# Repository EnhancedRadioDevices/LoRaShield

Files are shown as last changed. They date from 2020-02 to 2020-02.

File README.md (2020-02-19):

LoRaShield2.1 Hardware

These are the hardware design files for the LoRaShield2.1 electronics.

These hardware files were created with KiCAD. 
You may need the KiCAD libraries available here: https://github.com/mogar/KiCAD_libs
When opening these projects in KiCAD, you may need to change the path to the libraries from the above link.
This can be done in preferences->libraries in both the schematic editor and the layout editor.
Make sure the libraries noted there point to wherever you put the above KiCAD_libs repo.

# Arduino Library

Check out these libraries:

* https://github.com/EnhancedRadioDevices/LoRaHam
* https://github.com/EnhancedRadioDevices/LoRaChat

# LoRaShield 2.1 Pinout

LoRaShield uses the SPI pins on your Arduino. It also uses a couple of digital pins for reset and interrupt.

    Arduino <-> LoRaShield
    D2          interrupt
    D3          reset
    D10         SPI SS
    D11         SPI MOSI
    D12         SPI MISO
    D13         SPI SCK

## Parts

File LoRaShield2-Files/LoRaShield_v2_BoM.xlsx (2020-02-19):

Id | Designator | Package | Quantity | Designation | MFR | MFR PN | Supplier | Supplier PN
1 | C1 | C_0603 | 1 | 4u7 | Samsung Electro-Mechanics | CL10A475MP5LNNC | DigiKey | 1276-6684-1-ND
2 | C2,C6,C11 | C_0603 | 2 | 1u | Samsung Electro-Mechanics | CL10B105KP8NNNC | DigiKey | 1276-1946-1-ND
3 | C3,C7,C8,C9,C10 | C_0603 | 5 | 0u1 | Samsung Electro-Mechanics | CL10F104ZB8NNNC | DigiKey | 1276-1012-1-ND
4 | D1 | D_0603 | 1 | green LED | Lite-On | LTST-C190KGKT | DigiKey | 160-1435-2-ND
5 | J1 | SMA-EDGE-HandSolder | 1 | SMA_EDGE | DNP | DNP | DNP | DNP
6 | U1 | RFM98PW | 1 | RFM95PW - 915MHz | Hope RF | RFM95PW | Enhanced Radio Devices
6 | U1 | RFM98PW | 1 | RFM95PW -137MHz | Hope RF | RFM95PW | Enhanced Radio Devices
6 | U1 | RFM98PW | 1 | RFM95PW - 440MHz | Hope RF | RFM95PW | Enhanced Radio Devices
7 | C4,C5 | C_0603 | 2 | 6p | Samsung Electro-Mechanics | CL10C060CB8NNNC | DigiKey | 1276-2133-1-ND
8 | L2 | L_0603 | 1 | 18n | Murata | LQW18AN18NJ00D | DigiKey | 490-1172-1-ND
9 | J2 | Pin_Header_Straight_2x20_Pitch2.54mm | 1 | Conn_02x20_Odd_Even | DNP | DNP | DNP | DNP
10 | U2,U3 | USON-20_2x4mm_Pitch0.4mm | 2 | TXB0108DQSR | Texas Instruments | TXB0108DQSR | DigiKey | 296-27217-1-ND
11 | R1 | R_0603 | 1 | 1M | Rohm Semiconductor | ESR03EZPJ105 | DigiKey | RHM1MDCT-ND
12 | R2 | R_0603 | 1 | 330 | Panasonic | ERJ-3GEYJ331V | DigiKey | P330GCT-ND
13 | J3 | Pin_Header_Straight_2x06_Pitch2.54mm | 1 | Conn_02x06_Odd_Even | DNP | DNP | DNP | DNP
14 | R3,R5 | R_0402 | 2 | 0 | Vishay Dale | CRCW04020000Z0ED | DigiKey | 541-0.0JTR-ND
15 | R4 | R_0402 | 1 | DNP | DNP | DNP | DNP | DNP

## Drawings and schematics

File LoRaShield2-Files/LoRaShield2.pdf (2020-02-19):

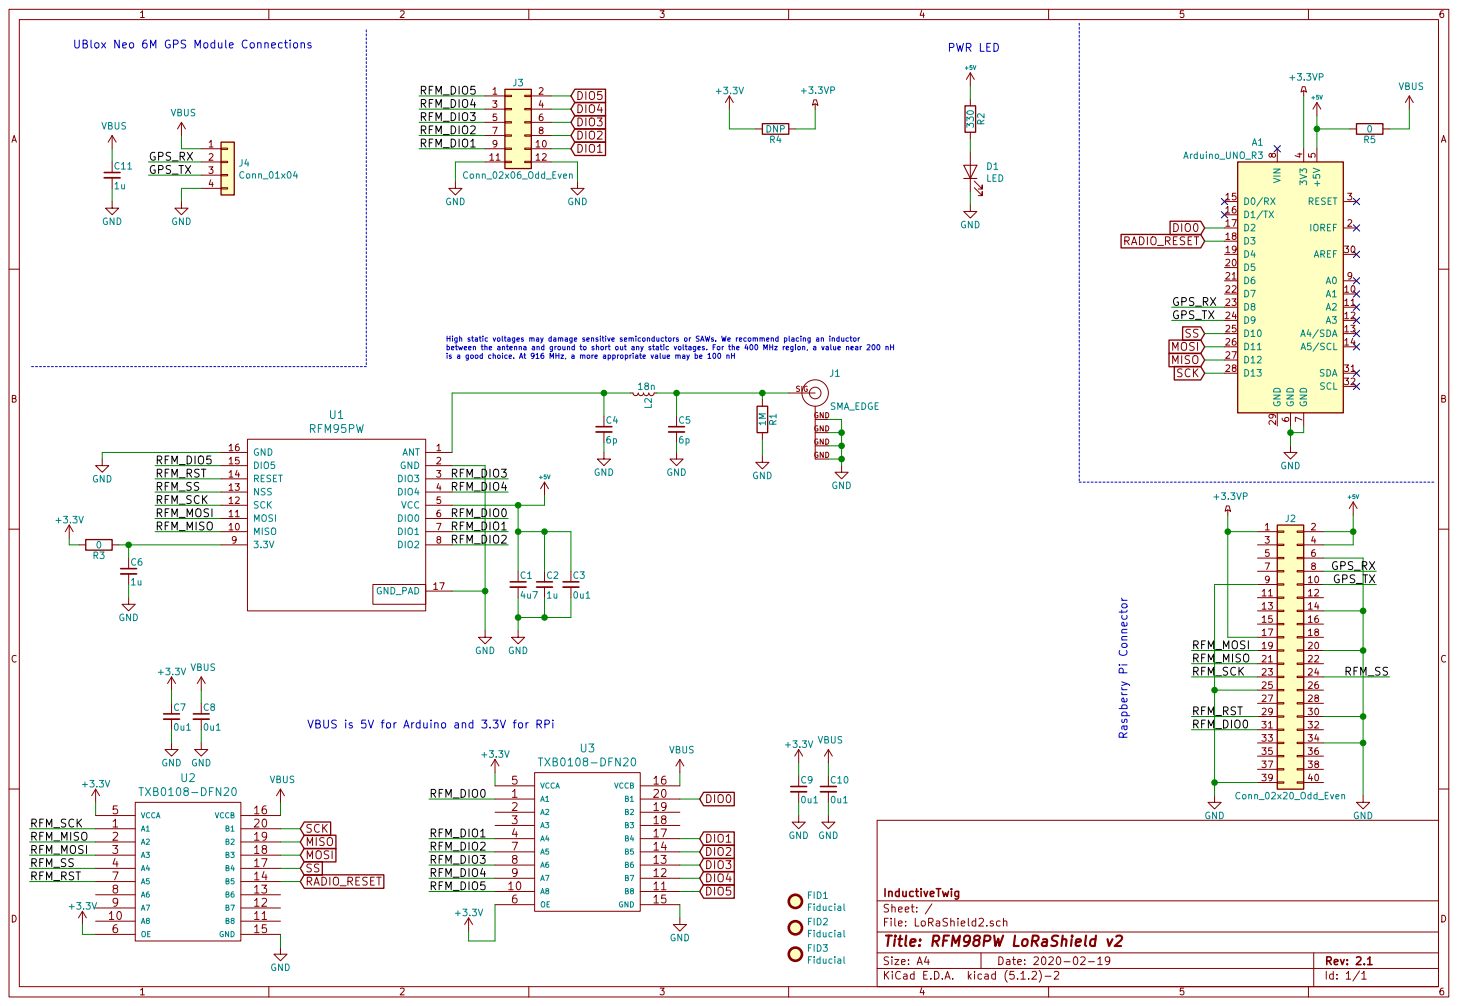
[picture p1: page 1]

UBlox Neo 6M GPS Module Connections VBUS C11

VBUS VBUS is 5V for Arduino and 3.3V for RPi VBUS

8 A0 9 A1 10 D5 20 AREF 30 A2 11 D6 21 SDA 31 A3 12 D7 22 SCL 32 A4/SDA 13 D8 23 A5/SCL 14 D9 24 D0/RX 15 D10 25 D1/TX 16 D11 26 D2 17 D12 27 D3 18 D13 28 D4 19 GND 29 A1 Arduino_UNO_R3 GND

High static voltages may damage sensitive semiconductors or SAWs. We recommend placing an inductor between the antenna and ground to short out any static voltages. For the 400 MHz region, a value near 200 nH

RFM_DIO3
RFM_DIO4

19 | | 20
21 | 22
23 | 26

31 | 32
33 35 37 39 | | 34

A5 7
A6 8

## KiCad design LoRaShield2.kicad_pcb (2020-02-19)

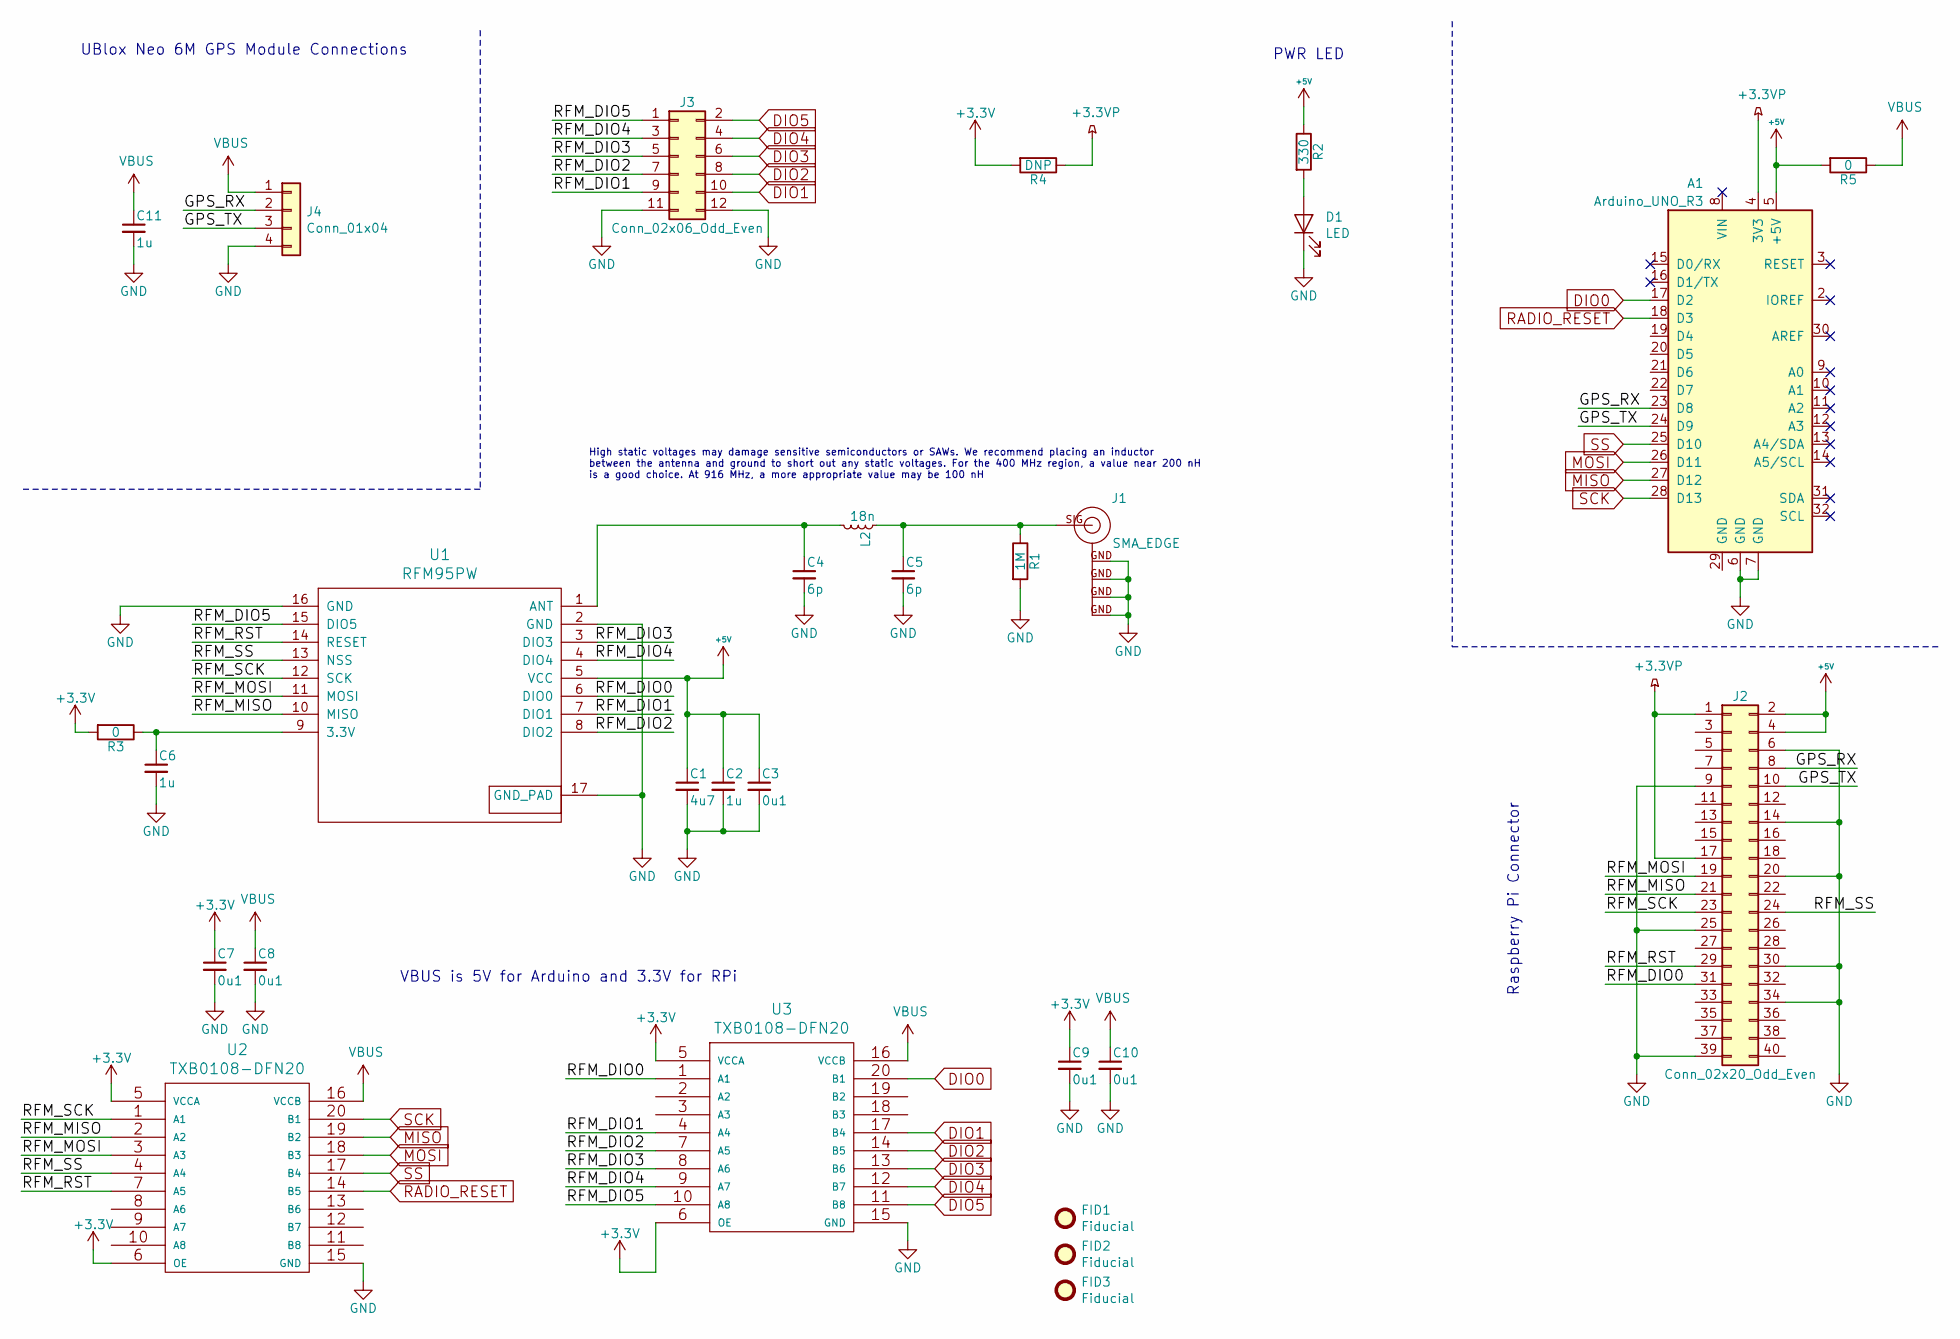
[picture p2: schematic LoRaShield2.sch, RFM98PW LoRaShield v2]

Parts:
A1: Arduino_UNO_R3; Arduino_UNO_HamShieldFootprint
C1: 4u7; C_0603
C2, C6, C11: 1u; C_0603
C3, C7, C8, C9, C10: 0u1; C_0603
C4, C5: 6p; C_0603
D1: LED; D_0603
FID1, FID2, FID3: Fiducial; Fiducial_0.5mm_Dia_1mm_Outer
J1: SMA_EDGE; SMA-EDGE-HandSolder
J2: Conn_02x20_Odd_Even; Pin_Header_Straight_2x20_Pitch2.54mm
J3: Conn_02x06_Odd_Even; Pin_Header_Straight_2x06_Pitch2.54mm
J4: Conn_01x04; Pin_Header_Straight_1x04_Pitch2.54mm
L2: 18n; L_0603
R1: 1M; R_0603
R2: 330; R_0603
R3, R5: 0; R_0402
R4: DNP; R_0402
U1: RFM95PW; RFM98PW
U2, U3: TXB0108-DFN20; USON-20_2x4mm_Pitch0.4mm

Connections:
+3.3VP: A1.4 (3V3), J2.1, J2.17, R4.1
+3V3: C7.1, C9.1, R3.2, R4.2, U2.5 (VCCA), U2.6 (OE), U3.5 (VCCA), U3.6 (OE)
+5V: A1.5 (+5V), C1.1, C2.1, C3.1, J2.2, J2.4, R2.1, R5.2, U1.5 (VCC)
/GPS_RX: A1.23 (D8), J2.8, J4.2
/GPS_TX: A1.24 (D9), J2.10, J4.3
/RFM_DIO0: J2.31, U1.6 (DIO0), U3.1 (A1)
/RFM_DIO1: J3.9, U1.7 (DIO1), U3.4 (A4)
/RFM_DIO2: J3.7, U1.8 (DIO2), U3.7 (A5)
/RFM_DIO3: J3.5, U1.3 (DIO3), U3.8 (A6)
/RFM_DIO4: J3.3, U1.4 (DIO4), U3.9 (A7)
/RFM_DIO5: J3.1, U1.15 (DIO5), U3.10 (A8)
/RFM_MISO: J2.21, U1.10 (MISO), U2.2 (A2)
/RFM_MOSI: J2.19, U1.11 (MOSI), U2.3 (A3)
/RFM_RST: J2.29, U1.14 (RESET), U2.7 (A5)
/RFM_SCK: J2.23, U1.12 (SCK), U2.1 (A1)
/RFM_SS: J2.24, U1.13 (NSS), U2.4 (A4)
DIO0: A1.17 (D2), U3.20 (B1)
DIO1: J3.10, U3.17 (B4)
DIO2: J3.8, U3.14 (B5)
DIO3: J3.6, U3.13 (B6)
DIO4: J3.4, U3.12 (B7)
DIO5: J3.2, U3.11 (B8)
GND: A1.6 (GND), A1.7 (GND), C1.2, C2.2, C3.2, C4.2, C5.2, C6.2, C7.2, C8.2, C9.2, C10.2, C11.2, D1.1 (K), J1.GND, J2.6, J2.9, J2.14, J2.20, J2.25, J2.30, J2.34, J2.39, J3.11, J3.12, J4.4, R1.2, U1.2 (GND), U1.16 (GND), U1.17 (GND_PAD), U2.15 (GND), U3.15 (GND)
MISO: A1.27 (D12), U2.19 (B2)
MOSI: A1.26 (D11), U2.18 (B3)
unnamed: C4.1, L2.2, U1.1 (ANT)
unnamed: C5.1, J1.SIG (SIGNAL), L2.1, R1.1
unnamed: C6.1, R3.1, U1.9 (3.3V)
unnamed: D1.2 (A), R2.2
RADIO_RESET: A1.18 (D3), U2.14 (B5)
SCK: A1.28 (D13), U2.20 (B1)
SS: A1.25 (D10), U2.17 (B4)
VBUS: C8.1, C10.1, C11.1, J4.1, R5.1, U2.16 (VCCB), U3.16 (VCCB)

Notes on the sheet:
High static voltages may damage sensitive semiconductors or SAWs. We recommend placing an inductor between the antenna and ground to short out any static voltages. For the 400 MHz region, a value near 200 nH is a good choice. At 916 MHz, a more appropriate value may be 100 nH
Raspberry Pi Connector
VBUS is 5V for Arduino and 3.3V for RPi
PWR LED
UBlox Neo 6M GPS Module Connections

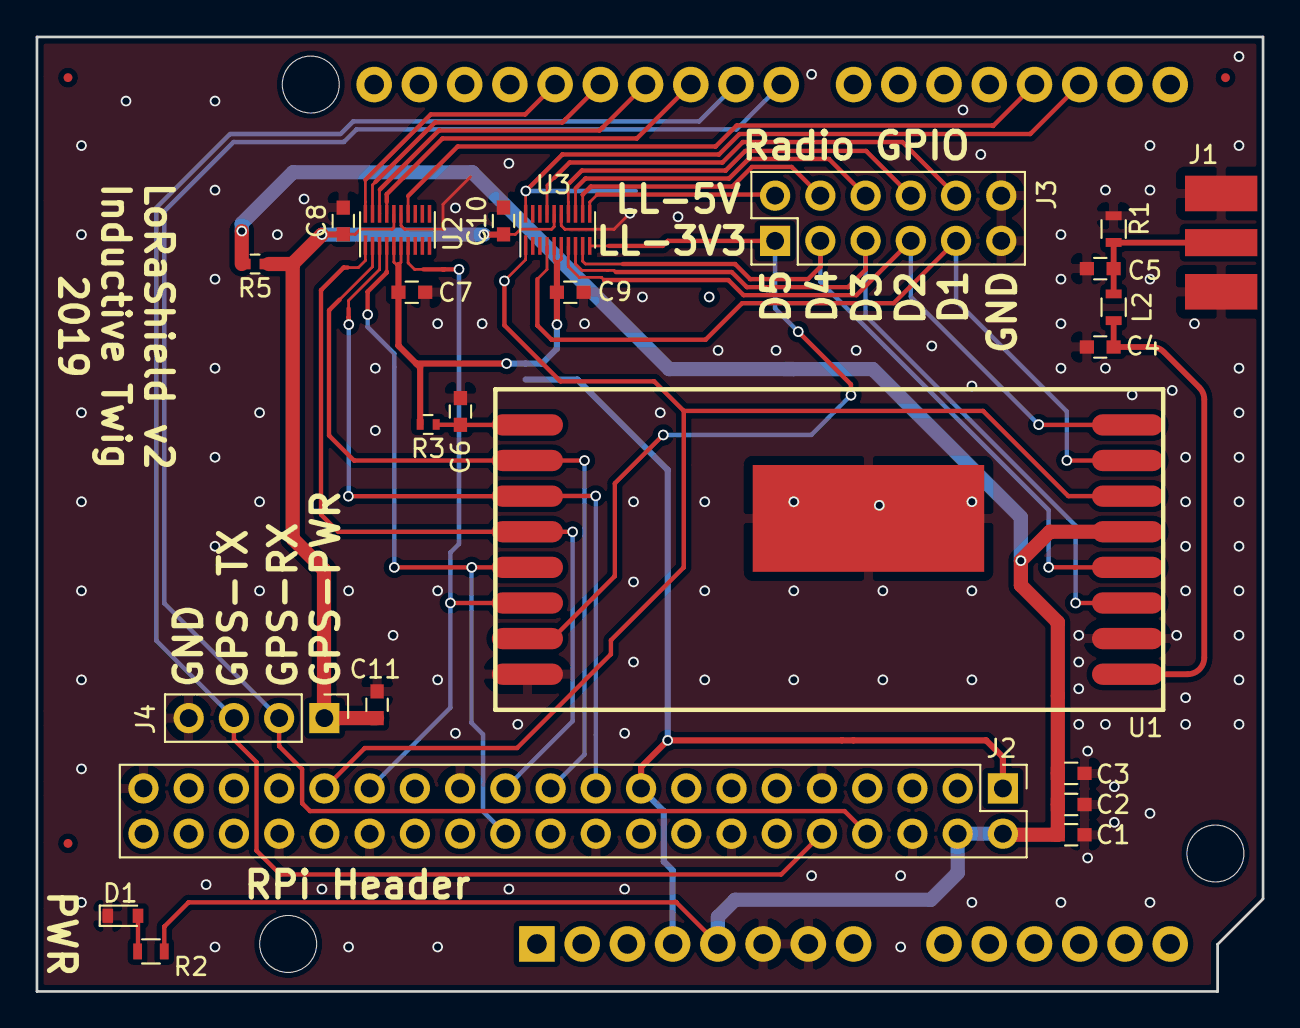
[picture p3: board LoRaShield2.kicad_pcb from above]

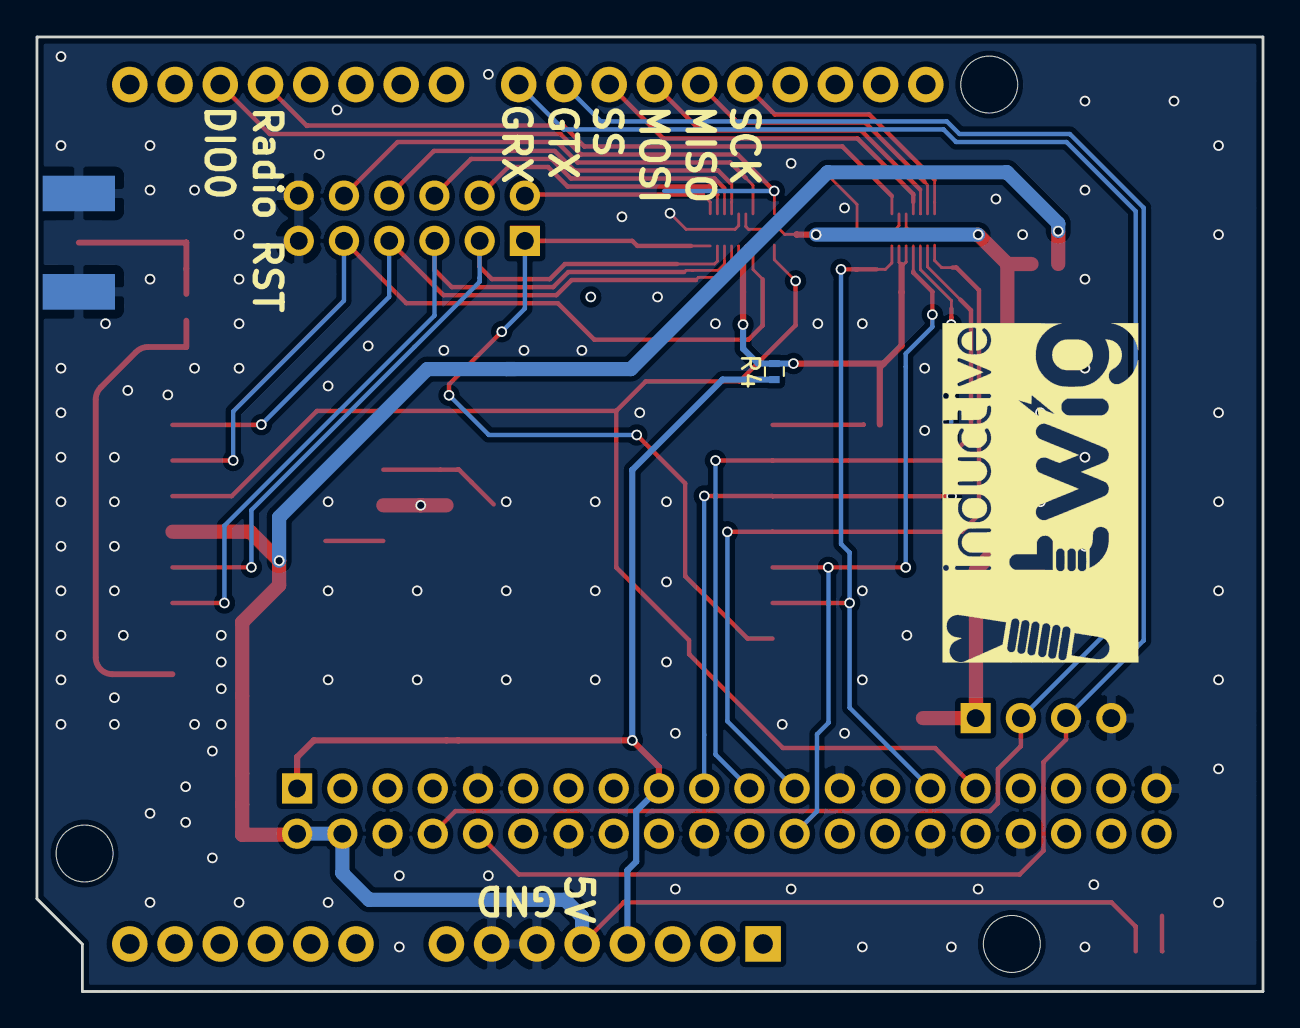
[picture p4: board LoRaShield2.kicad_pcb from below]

Board: 4 copper layers, 68.9 x 53.6 mm, 29 parts (2 on the bottom side), 33 nets.

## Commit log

2019-05-01 commiting hw files
    [LoRaShield-B.Cu.gbl, LoRaShield-B.Mask.gbs, LoRaShield-B.Paste.gbp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]
2019-05-01 update files
    [LoRaShield-B.Cu.gbl, LoRaShield-B.Mask.gbs, LoRaShield-B.Paste.gbp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]
2019-05-01 fab files added
    [LoRaShield_v1.2_BoM.xlsx]
2020-02-19 update to rev2.1
    [LoRaShield.kicad_pcb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]
